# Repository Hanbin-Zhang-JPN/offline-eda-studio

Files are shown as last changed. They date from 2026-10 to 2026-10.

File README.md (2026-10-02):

# Offline EDA Studio

面向 MacBook 的原生、离线 EDA 工作台。项目目标是在明确的验收矩阵上达到 Altium Designer **90% 以上**功能覆盖；当前交付是 **v0.1.1 可运行基础版本与完整开发设计，不是已经达到 90% 的替代软件**。

原理图、PCB 编辑、交互布线、3D 与仿真使用本地 KiCad 引擎。SwiftUI 工作台补充项目管理、采购 BOM、点对点线束、SHA-256 快照和制造发布流水线。工作台没有网络客户端、云账号、遥测或在线激活。

## 当前可运行的功能

- 原生中文 macOS 界面与 CLI，打开/创建自包含项目，启动 KiCad 原理图和 PCB 编辑器。
- PCB 简化只读预览：真实文件里的直线、走线和矩形焊盘，前/后铜层切换。
- 本地采购元件增删、搜索、计划 DNP、分组 CSV。采购计划不自动同步原理图；设计 BOM 从 KiCad 导出。
- 点对点线束检查与裁线 CSV：未知连接器、越界引脚、重复占针、自连接及长度检查。
- 复制前后校验的项目快照，SHA-256 清单与篡改检测。
- KiCad 作业：ERC、DRC/原理图一致性、Gerber、Excellon、坐标、STEP、SVG、PDF、网表、设计 BOM、IPC-2581、ODB++。
- 双层板制造发布：冻结输入 → 检查 → 输出 → 校验，失败保留诊断。多层板明确拒绝，避免遗漏内层铜。
- 薄导体微带阻抗初估，带参数检查与模型限制。
- 12 类、122 项功能矩阵及每项验收条件。矩阵中的继承能力、代码实现与完整验收分开记录。

## 获取和安装

要求 macOS 14 或更高。当前发布的工作台二进制为 Apple Silicon（arm64）；Intel 需自行编译，尚未完成硬件验收。

1. 从 [Releases](https://github.com/Hanbin-Zhang-JPN/offline-eda-studio/releases) 下载工作台 ZIP，解压，将 `Offline EDA Studio.app` 放进“应用程序”。
2. 从 [KiCad 官方 macOS 下载页](https://www.kicad.org/download/macos/) 获取 KiCad 10.x，按官方说明安装完整 KiCad 文件夹，保留内置符号、封装及 3D 模型。验证基线为 10.0.6。
3. 打开工作台，默认自动查找 `/Applications/KiCad/KiCad.app/Contents/MacOS/kicad-cli`。自定义安装位置可用“选择 EDA 引擎”。
4. 点击“新建示例”，选择新目录；打开原理图或 PCB 编辑器，编辑并保存后回到工作台刷新。
5. 准备好本地模型后断网，检查、快照、CSV 和制造输出仍可运行。演示项目自带原创符号与封装，演示检查不依赖外部元件库。

工作台包使用本地 ad-hoc 签名，尚未 Developer ID 签名和公证。首次启动可在 Finder 右键“打开”，由 macOS 安全设置决定是否允许；不要求关闭系统保护。工作台 ZIP 不含 KiCad 二进制，完整离线安装需提前准备 **两个包**及所需模型。仓库提供固定版本下载和 SHA-256 校验脚本。

## 从源码编译

安装 Xcode Command Line Tools（或 Xcode）、Python 3；Swift 5.9+。无 npm、第三方 Swift 包或在线运行时依赖。首次安装开发工具需要网络；准备好的源码可离线编译。

```bash
./scripts/prepare-resources.sh
./scripts/swift.sh build
./scripts/swift.sh run EDASelfTests
./scripts/build-app.sh
open "dist/Offline EDA Studio.app"
```

`scripts/swift.sh` 会在本机 CLT 的预览 SDK 缺少 State 宏插件时选择已安装的稳定 SDK；可通过 `EDA_SDK=/path/to/sdk` 显式指定。产物在 `dist/`。测试程序不依赖完整 Xcode 中的 XCTest，可在 CLT 环境运行。

## CLI

```bash
.build/debug/eda create /tmp/led-design "我的 LED 板" examples/led-demo
.build/debug/eda doctor
.build/debug/eda inspect /tmp/led-design
.build/debug/eda snapshot /tmp/led-design "布局完成"
.build/debug/eda bom /tmp/led-design /tmp/planning-bom.csv
.build/debug/eda harness /tmp/led-design /tmp/wires.csv
.build/debug/eda job /tmp/led-design drc /tmp/check
.build/debug/eda release /tmp/led-design --step
.build/debug/eda impedance 0.30 0.18 4.2
```

可以用 `KICAD_CLI=/path/to/kicad-cli` 指定引擎。制造发布的 `release.json` 包含源哈希、输出哈希、引擎版本、命令、日志与退出码。`outputs/job-*` 是单项输出，**不等于通过发布**。`outputs/failed-*` 是诊断目录。

## 实现边界

高级 SI/PI 场求解、复杂刚柔结合、多板 3D 装配、正式装配变体、受管元件库、Draftsman 等效文档和原生 Altium 无损往返尚未完成。上游编辑器的功能存在不意味着本仓库已经逐项验收。当前预览不显示全部 PCB 几何；采购计划 DNP 不修改 KiCad 变体；输出检查不能替代独立 DFM 或器件电气验证。

v0.1 发布流水线只支持双层板，使用启用的 KiCad 规则。报告中的 `ignored_checks` 列出关闭的检查；没有“自动绕过检查”的按钮。复杂项目中的外部库/3D/SPICE 依赖目前需手工准备，完整依赖锁定属于后续阶段。

## 仓库地图

|路径|内容|
|---|---|
|`Sources/EDACore`|项目、BOM、快照、线束、解析预览、KiCad 适配与制造门禁|
|`Sources/EDAStudio`|原生 SwiftUI 桌面应用|
|`Sources/EDACLI`|命令行入口|
|`Tests/EDACoreTests`|可独立运行的核心测试|
|`examples/led-demo`|可复生成的原创、自包含 KiCad 示例|
|`Resources`|功能矩阵数据和类别权重|
|`docs`|需求、系统架构、各高级模块规格、路线图、离线打包及验收|
|`scripts`|构建、校验、引擎下载、真实集成测试和资源同步|
|`reports`|本次验证证据及限制|

## 设计与验收文档

从 [产品需求](docs/PRODUCT_REQUIREMENTS.md)、[系统架构](docs/ARCHITECTURE.md)、[122 项功能矩阵](docs/FEATURE_MATRIX.md) 和 [分阶段路线图](docs/ROADMAP.md) 开始。具体模块规格位于 [docs/specs](docs/specs)，当前运行说明见 [macOS 安装](docs/MACOS_INSTALL.md)、[离线使用](docs/OFFLINE.md)、[测试方案](docs/TESTING.md)。

本项目与 Altium、KiCad 官方无从属关系。原创代码和示例为 MIT 许可；外部引擎保留各自许可证，见 [第三方说明](THIRD_PARTY.md)。

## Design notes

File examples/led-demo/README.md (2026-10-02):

# 自包含 LED 示例

原始演示数据，符号与封装均由本仓库生成，不依赖外部元件库。J1.1 为 3.3 V 输入，J1.2 为地；R1 330 Ω 与 D1 串联。图形是通用两引脚演示符号，未替代真实 LED 符号及器件电气模型。板上封装、极性、电流与器件料号必须按实际采购器件重新设计和验证，不可直接投产。线束数据为独立点对点示例，J2 是外部电源连接器。采购单价 0 表示未录入报价。

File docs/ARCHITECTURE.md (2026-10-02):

# 系统架构

## 已实现架构

```mermaid
flowchart LR
    UI[SwiftUI macOS 工作台] --> Core[EDACore]
    CLI[eda CLI] --> Core
    Core --> Data[项目 JSON / SHA-256 快照]
    Core --> Runner[参数数组 / 超时 / 日志文件]
    Runner --> Engine[KiCad 10 CLI]
    UI --> Editors[KiCad 原生编辑器]
    Engine --> Outputs[报告 / 制造文件 / 三维导出]
```

工作台没有 HTTP/WebSocket 客户端或服务端。进程适配器直接运行本地二进制，使用参数数组避免 shell 注入，stdout/stderr 写临时文件防止管道缓冲死锁。检测超时后先 terminate，必要时 kill 并等待子进程退出。GUI 将耗时工作放到后台任务，不在主线程执行 DRC。

### 模块职责

|模块|责任|禁止行为|
|---|---|---|
|Models|schemaVersion、路径边界、元数据原子保存、BOM 分组|重写原理图或隐式改料|
|ProjectFiles|排除生成目录、复制前后哈希、快照校验|跟随符号链接把外部文件打包|
|Harness|连接器/针脚/导线数据与点对点检查|假定独立线束已同步 PCB|
|BoardPreview|有边界的 S-expression 解析和几何摘要|用于制造或电气拓扑判定|
|Engine|引擎探测、版本握手、CLI 作业、日志与超时|默认兼容未知主版本|
|Manufacturing|冻结、规则检查、证据校验、唯一发布目录|把失败输出标为 release|
|AppModel|最近项目、文件选择、后台作业、编辑器启动|上传项目或自动下载依赖|

### 设计权威与一致性

`.kicad_sch/.kicad_pcb/.kicad_pro` 是设计权威文件。工作台元数据、采购计划、线束资料独立存储。当前 DNP 仅作用于采购计划，原理图权威 BOM 独立导出。发布 DRC 包括 `--schematic-parity`，但程序不能代替器件电气、工艺能力和人工批准。

当前 Snapshot 将所有非生成源文件复制进不可变目录，并核对复制前后和目标的散列；恢复时用户复制 source 到新目录。复杂外部依赖尚未自动解析，不可宣称完整工程闭包。

## 目标架构（待实现）

```mermaid
flowchart TB
    Desktop[SwiftUI / AppKit] --> Service[项目与设计服务]
    Service --> DB[可重建 SQLite 索引]
    Service --> Registry[本地受管库 / 内容寻址资源]
    Service --> Jobs[任务依赖图 / 发布审计]
    Service --> IPC[KiCad IPC 文档化适配器]
    Service --> Advanced[约束 / 变体 / 线束 / 多板 / 刚柔]
    Advanced --> Geometry[OCCT 几何与碰撞进程]
    Advanced --> Solver[本地 SI/PI/SPICE 适配器]
    Jobs --> Package[离线交付清单 / SBOM / 签名]
```

1. 服务层使用 actor 隔离项目操作；每个项目单写者，读取使用明确 revision ID。
2. 原生设计文件保存后计算 design revision；所有结果绑定 revision、库锁文件、规则哈希和引擎版本。
3. 任务图按输入签名缓存，但任何门禁结果不得跨不同源/库/规则复用。
4. 几何、仿真、插件独立进程；崩溃或许可证缺失不会损坏原生项目。
5. IPC 支持启动握手、API 能力查询、事务回执和保存确认；不足的 API 继续走受审查 CLI 或原生 GUI。
6. SQLite WAL 用作索引与审阅事件存储；设计本身仍是开放文件。事务失败不改变审批状态。

### 高级模块依赖顺序

库锁定 → 项目闭包 → 正式变体 → 制造完整性；原生语义抽取 → 约束 → 高速求解；OCCT 模型 → 碰撞 → 多板/弯折；系统端口 → 线束/跨板 ECO。任何一个模块只提供 JSON 模型不算完成图形编辑/专业校核。

### 项目服务 API（目标）

`openProject(URL) -> Revision`；`scanDependencies(Revision) -> ClosureReport`；`proposeECO(ChangeSet) -> Preview`；`commitECO(Preview, expectedRevision)`；`runJob(JobSpec, Revision) -> JobID`；`approveRelease(Hash, Identity)`；`exportBundle(Revision, Lockfile)`。所有写入携带 expectedRevision，防止覆盖外部编辑器的新保存。

### 可替换组件

引擎通过协议提供探测/版本/能力/作业/编辑器接口；不得将 KiCad 内部未公开类直接嵌入 SwiftUI。三维/求解器也通过声明式输入文件与结果 schema 通信，选择后锁定版本和单位。任何生成规则/仿真约束回写先出差异预览。

### 已知工程债

工作台当前使用全文件读取、数组型采购计划和极简预览；大型工程需要流式解析/索引。作业暂不可主动取消；只有超时。外部库闭包/恢复事务/多层出图/完整 DFM/批准签名尚未实现。不得把这些债项隐去以宣称 90%。

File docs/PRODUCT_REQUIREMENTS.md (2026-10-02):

# 产品需求与边界

## 产品目标

为 MacBook 提供无需联网、账号或激活的电子产品设计工作流。从捕获电路、元件选择、多层 PCB、布线、验证、3D、装配变体、制造文档到本地版本审阅保持数据可追溯。KiCad 原生文件为单板设计权威数据，工作台不能通过自建简化格式取代电气设计。

“Altium 90%”的分母由 FEATURE_MATRIX 冻结，须由需求方认可。只对具有完整验收证据的功能计分；简单子功能数量不能冲抵复杂能力。12 类均须达到最低分数，关键高阶能力须全部通过。v0.1 当前不做达标宣称。

## 用户场景

1. 普通硬件工程师：带着已准备好的库断网，在 Mac 创建原理图、布线并交付双层/多层板。
2. 高速工程师：层叠、阻抗、差分/延时组约束、仿真证据与走线对应；不把近似计算器当场求解器。
3. 机电工程师：壳体与板框交换、装配位置变更、碰撞/干涉检查和批准事务。
4. 小型团队：本地库批准、设计快照、语义比较、评论、审批，网络同步是可选显式动作。
5. 制造工程师：读取制造网表、所有层、孔表、坐标、BOM、装配变体与可验证的交付清单。

## 当前范围（v0.1）

本地工作台、两层自包含示例、采购计划、点对点线束、不可变快照、KiCad CLI 适配和检查门禁。原生编辑发生在外部 KiCad 应用中；用户保存后刷新。单项作业输出、正式发布目录和失败诊断目录具有不同语义。

## 目标范围（待实现）

四层以上制造流水线、完整依赖锁定/迁移、正式装配变体、受管库、IPC 编辑事务、约束管理、多板装配、刚柔区域和折叠、线束图形编辑、SI/PI 求解集成、生产文档生成、离线审阅/批准。实时供应链服务不能离线等效，只支持带时间戳的导入镜像。

## 非功能指标（目标，尚未实测验收）

|项目|目标|
|---|---|
|平台|macOS 14+，arm64 和 x86_64 独立验证|
|安装|签名/公证 app；离线完整包有 SHA-256 和 SBOM|
|启动|基准 16 GB M 系列机器，空工作区冷启动 ≤3 秒|
|交互|常规 5000 元件 PCB 交互保持 ≥30 FPS；更大项目提供降级/分页|
|索引|10 万元件搜索 P95 ≤150 ms，事务与索引可重建|
|制造|输出哈希可重复；时间戳或引擎非确定字段明确分离|
|安全|不运行 shell 拼接字符串；越界路径/不受信插件可拒绝|
|网络|断网核心流程全通过，无隐式远程下载/遥测|
|保全|原子保存、快照校验、磁盘满/崩溃/超时测试无设计覆盖|
|可访问性|键盘、VoiceOver、中文/英文、缩放和高对比度|

## 数据所有权

项目为用户可直接读取的目录，元数据 JSON、设计为 KiCad 原生文件、未来索引 SQLite 为可重建副本。禁止强制云格式、暗中更换元件库和自动上传电路。程序不得将“导入成功”表述为“电气等价”，必须输出差异报告。

## 完成判定

完整闭环不是仅有按钮：需要正/负夹具、导出独立验证、断网测试、Mac 两架构安装测试、清洁机器迁移、故障注入与需求签收。详细门禁见 TESTING。未完成項目不能在功能矩阵里标为 verified。

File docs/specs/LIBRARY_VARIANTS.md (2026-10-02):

# 受管元件库、采购和装配变体

状态：v0.1 为手工采购计划；专业管理与正式变体待实现。

## 三种对象必须分开

- DesignComponent：原理图/PCB 的权威实例，包含网络、封装和电气属性。
- ProcurementPlan：参考位号、MPN、厂商、离线报价和库存。当前 parts.json 即此对象。
- AssemblyVariant：指定设计 revision 上的 DNP/替代料规则，必须同时作用于坐标、BOM、装配图、3D 与制造文档。

采购计划删除/DNP 不改变原理图。正式变体解析器输出 EffectiveAssembly，并被所有作业共用，不允许每个导出脚本独立解释 DNP。

## 本地受管库（目标）

元件 UUID 的每个批准 revision 绑定符号/封装/模型内容哈希、参数单位、生命周期、来源/许可、数据表和审核记录。草稿可以编辑，批准版本不可原地改变；项目通过锁文件引用 revision。SQLite 搜索索引可重建，资源以内容寻址保存。

参数含数量、单位、容差与比较区间；检索结果区分 unknown 和 zero。批准替代料要满足封装/焊盘映射、额定值、容差、温度和高度约束。MPN 字符串相近不能自动替换。

## 离线报价

QuoteSnapshot：供应商、币种、单位、阶梯数量、包装、最小订购量、库存、采集时间、来源。用户主动导入，显示时效；缺报价不计算为 0 成本。批次计算包含单位数量、损耗和包装取整，公式和币种转换资料可审查。不承诺断网实时 ActiveBOM。

## 必需异常测试

重复位号/跨板 ID、引号和换行字段、同 MPN 不同封装、价格分组、缺币种、替代料针脚错配、DNP 坐标遗漏、多变体导出错用、库锁缺失和批准记录冲突。清洁 Mac 不配置全局库即可重开锁定工程。

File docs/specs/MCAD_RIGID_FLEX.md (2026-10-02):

# 三维、机电与刚柔结合

状态：KiCad 提供本地 3D/STEP 导出，工作台可执行 STEP 作业；复杂机电协同与刚柔设计待实现。

## 几何基础

建议独立 OCCT 服务进程，输入为锁定 STEP 模型、板框、叠层、元件变换和公差。统一 mm 与右手坐标系；变换使用明确 4×4 矩阵，所有源坐标转换可追溯。模型缺失显示占位和诊断，不把没有模型的空间当无碰撞。

实体/面选择锚点不能只用导入时的数组下标，需关联设计 UUID 与稳定几何签名。引擎更新后拓扑改变的锚点标记失效。

## 双向 ECO

板框/孔/元件位置 → MCAD → 提案 → 差异预览 → 容差/约束检查 →批准 → 原生设计提交。来自外部机械工具的修改必须携带 revision/模型哈希；PCB 已变化时不直接合并。STEP 交换本身不是实时 CoDesigner 等价能力。

## 刚柔区域模型

Stackup 记录铜/介质/覆盖膜/加强片的材料、厚度、层范围与压合序列；Region 为可验证多边形、子叠层 ID、刚/柔类型和优先级；Bend 包含轴、半径、角度、顺序、适用区域与中性面参数。重叠/嵌套区不能用单一板厚处理。

展开/折叠在固定坐标映射上变换几何，保留元件/铜/孔锚点。通过材料厚度和弯曲半径计算路径，但柔性材料的真实力学可靠性需要工程规则与厂商验证，不由 3D 外观决定。

## 检查

区域无意重叠/未覆盖、层集合冲突、柔区过孔和尖角、弯折区元件/铜规则、折叠实体干涉、最小弯折半径与覆盖膜开口。输出展开轮廓、分区叠层、覆盖膜、加强片和钻孔/压合组，与制造商黄金资料对照。

## 多板装配

每个 board instance 具有 designRevision、变换和连接器锚点；配合约束包括平面、同轴、距离、角度和端口。约束图避免环形过约束，求解失败有解释。装配碰撞与系统连接图同 revision，不可用旧板模型批准新系统。

## 关键验收

STEP 独立导入和单位核对、已知干涉/间隙、模型缺失、PCB 外部编辑冲突；单/多弯折、重叠子叠层、开槽与书本结构、展开恢复、刚柔制造文件。未实现折叠/制造映射前，FLEX 类保持 planned。

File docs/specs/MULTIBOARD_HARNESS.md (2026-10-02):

# 多板系统与线束

状态：v0.1 有独立点对点数据、检查和裁线 CSV，没有多板 3D 和线束图形编辑。

## 系统数据

SystemProject 包含 BoardInstances、Ports、Interconnects 和 Assembly。每个端口绑定板实例 ID、元件 UUID、针脚映射、信号类型、电压/电流等级及匹配接插件；跨板重复位号用 BoardID:Reference 区分。网络名相同不自动意味着系统连通。

连接类型：直接板对板、线缆、线束、柔性连接；都须有针脚对照和电气类型检查。板接口 ECO 改动触发相关线束/系统连接过期，制造发布需重新审核。

## 线束专业模型

Connector 的引脚、壳体、端子和防呆方向；Wire 的线径、绝缘、颜色、长度和公差；Splice 作为显式分支节点；Shield、TwistedPair、Sleeve、Branch 与 TerminalCrimp 独立对象。导线长度分开路由几何长度、加工余量和裁线长度，计算规则可审查。

v1 的重复占针拒绝用于点对点；未来支持分支必须通过 Splice，不直接放开唯一性规则。检查包含未知端点、引脚越界、自连接、错误网、端子兼容、接插件性别/方向、额定电压电流、线径与压接范围、屏蔽接地及分支连接。

## 图形编辑与文档

2D 系统连接/线束路由编辑支持选择、吸附、弯折/分支、撤销事务、端口高亮和电气问题定位。制造图提供端面朝向、线色/针脚/端子、套管、长度公差、压接和治具资料；裁线 CSV 只是其中一项。

## ECO

板连接器改变 → 系统端口差异 → 线束受影响对象 → 可审查修复映射 → 系统/板/线束统一批准 revision。不能仅按名字猜测针脚；未分配针脚与错配作为阻塞问题。

## 验收

直连/交叉针脚、重复板、错误性别、越界、线径压接、分支/屏蔽/绞对、线长/余量、接口版本冲突、BOM 聚合、3D 端口映射与制造图核对。当前演示 J2 是外部连接器，数据尚未自动与 PCB 原理图同步。

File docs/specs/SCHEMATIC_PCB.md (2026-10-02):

# 原理图、PCB 与约束规格

状态：单板编辑使用 KiCad；以下专业流程待逐项验收或实现。

## 权威数据与编辑

SchematicDocument 保留符号 UUID、层次页路径、引脚、电气类型、总线/网络名与元件字段。BoardDocument 保留封装 UUID/原理图 path、铜层、焊盘、走线、过孔、区域、叠层和规则。工作台预览只读，不得参与网络抽取；权威网表和 DRC 由引擎提供。

IPC 服务启动时查询能力与主版本，提交事务携带 expectedRevision 和操作列表，成功后要求保存回执、重新读取网表/哈希。多窗口编辑有外部文件变更检测；冲突不以时间戳更近自动取代。

## ECO 流程

原理图修改 → 网表/封装映射提取 → 新增/删除/改值/改封装/改网的差异预览 → 用户批准 → 引擎提交 → ERC/DRC/一致性检查 → 保存新 revision。删除元件不能悄悄留下无主铜；换封装必须审查焊盘映射和三维高度。

## 约束模型

ConstraintSet：网络类、对象选择器、区域、适用层、优先级、值及单位。规则冲突采用确定性顺序：显式对象规则 > 区域规则 > 网络类 > 全局默认；未实现前使用原生引擎规则。每个对象可查询规则命中的解释。

包含线宽、铜距、孔径/环宽、层对、差分间距/偏差、线长、延时组、禁布/禁高、阻焊/钢网。延时不是简单几何长度，需要介质、层叠、过孔和求解模型；无法评估时报告 unsupported，禁止推断通过。

## 多层制造

导出时从板配置枚举所有启用的铜层和工艺层，核对 Gerber 数量/层名、钻孔层对和叠层声明。盲埋/微孔记录压合组；板形、槽孔、工艺边进入文档。v0.1 只允许 F.Cu/B.Cu，四层以上必须在原生 KiCad 审核导出，直到多层漏层负测试通过。

## 专业验收

层次/总线/多单元黄金网表；BGA 推挤和撤销；差分过孔、蛇形线长/延时；HDI 层对；覆铜热连接与孤岛；4/16/32 层制造包；10 万焊盘性能；跨探测和编辑器保存回执。文件可读、图形漂亮或单板零违规都不足以完成这些验收。

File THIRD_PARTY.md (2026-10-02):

# 第三方组件与来源

本仓库原创 Swift 代码、生成脚本、文档、符号/封装与示例采用 MIT。SwiftUI、AppKit、Foundation、CryptoKit 是系统框架，本仓库不分发其源码或系统运行时。

KiCad 是独立外部引擎，工作台通过文档化命令行和外部应用入口调用，不包含 KiCad 源码或可执行文件。官方 DMG 通过 fetch-engine.sh 单独获取，engine/ 被 Git 忽略，不随工作台 ZIP/GitHub 源码发布。KiCad 及其内置 Python、wxWidgets、ngspice、几何与其他资源的许可声明以官方安装包和上游源码为准；重新捆绑引擎必须保留全部相应许可和源码提供要求，不能把引擎改称本项目 MIT 代码。

固定引擎来源：

- [KiCad 10.0.6 官方 Release](https://github.com/KiCad/kicad-source-mirror/releases/tag/10.0.6)
- 文件：kicad-unified-universal-10.0.6.dmg
- SHA-256：ef4dcd4278c46d3efcd28c8db273d5957d68efda028f6bf79b4811fc5302dc68
- [KiCad macOS 安装](https://www.kicad.org/download/macos/)
- [KiCad CLI](https://docs.kicad.org/10.0/en/cli/cli.html)

Altium Designer、Altium 与 KiCad 商标属于各自权利人。没有复制 Altium 商业代码、图标、界面素材或示例，文档只进行功能范围对标，不宣称官方认可。未来第三方求解器/几何/库资源应增加 SPDX、来源和 SBOM；当前仅是设计规格，未暗中下载这些组件。

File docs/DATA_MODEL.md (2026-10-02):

# 数据模型与存储

## 已实现格式

项目目录至少包含 eda-project.json、设计文件、parts.json、harness.json。manifest schemaVersion=1，name 不为空，所有字段均为项目内相对路径。绝对路径、`..`、解析到根外的符号链接被拒绝。设计文件使用 KiCad 原生格式，不由工作台更改电气结构。

```json
{"schemaVersion":1,"name":"LED","projectFile":"design.kicad_pro","schematicFile":"design.kicad_sch","boardFile":"design.kicad_pcb","partsFile":"parts.json","harnessFile":"harness.json"}
```

parts.json 是 Component 数组：reference/value/footprint/mpn/manufacturer/unitPrice/dnp。每个位号一条，忽略大小写的重复位号拒绝；价格必须非负有限数。数量由分组得到，组键包含值、封装、MPN、厂商、单价及 DNP。单价当前没有币种，是采购计划字段，不能作为实时采购计算。

harness.json 包含 schemaVersion、connectors 与 wires。连接器有 id/pins/partNumber；导线有 id/from/to/net/lengthMM/awg/color。v1 是点对点模型，一个端点不允许被多根线占用；分支需要未来显式接点模型，不能靠重复占针代替。

### 快照

`.eda-snapshots/<uuid>/snapshot.json` 记录时间、标签、每个源文件路径/字节数/sha256，source/ 复制源。排除 outputs、快照自身、Git、构建产物、引擎、备份和 KiCad 临时偏好文件。复制前后输入以及复制目标必须一致，不一致则清理临时目录。校验要求文件集合也一致，新增/删除/修改均导致失败。

### 作业与发布

单项作业：outputs/job-*/command.json。发布：outputs/release-*/release.json + source/ + artifacts/；失败：outputs/failed-*。命令含参数、退出码、stdout/stderr、耗时。发布清单包含源/输出哈希、引擎版本、status 与 note。UUID 命名确保不同运行不覆盖输出。

元数据使用原子写入。当前无多进程写锁，外部同时修改 parts.json 可造成最后写入胜出；生产级项目 actor 和 expectedRevision 属于 P2，不能声称已解决并发编辑。

## 未来服务数据模型

|实体|关键字段|不变量|
|---|---|---|
|DesignRevision|source hashes、libraryLockHash、ruleHash、engineVersion|审批和结果绑定相同 revision|
|ManagedComponent|UUID、revision、symbolHash、footprintHash、modelHash、parameters、status|批准版本不可原地覆盖|
|Variant|baseRevision、component overrides、DNP、alternative ID|每种输出采用同一个变体解析结果|
|ECO|expectedRevision、operations、previewHash、author|提交前验证 revision，无静默冲突|
|Assembly|board instance ID、4x4 transform、mates|坐标/单位统一、禁止循环配合|
|FlexRegion|polygon、stackup ID、bend definitions|区域与层集合明确，展开/折叠可逆|
|ReviewEvent|object anchor、revision、identity、time、action|失效锚点不能错误指向新对象|
|JobSpec|input hashes、capabilities、tool version、outputs|缓存键包括所有设计/依赖/规则|

SQLite 仅作索引、可重建视图与审阅事件，启用 foreign keys/WAL 和事务。几何使用 KiCad 原生精度或整数 nm；求解器边界转换用显式单位，不能混用 mil/mm。文件 schema 迁移先备份再生成新版本，不原地升级用户原稿。

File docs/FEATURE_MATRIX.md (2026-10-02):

# Altium Designer 功能对标与验收矩阵

基线：2026-10-03 阅读的官方功能资料；不是 Altium 官方的全量功能目录或等效认证。

**目标 ≥90%，当前尚未达成。** status 为 implemented 表示已有代码；inherited 表示引擎拥有相关能力但没有完成本仓库验收；planned 表示只有规格。只有 verified 状态且证据包含版本、平台、正常/异常夹具、人工验证与可复现结果时，才计入验收覆盖率。单个 LED 示例通过不代表完整生产级能力通过。当前所有功能仍待完整验收，因此验收分数为 0%，这不代表引擎没有功能。

## 计算方法

每个类别内按 weight 加权，再按类别占比汇总。分母冻结，不移除难题或把云能力悄悄排除。支持的离线等效流程需单独验收，不能称实时服务等效。

`总分 = Σ 类别占比 × Σ(功能权重 × verified) / Σ(功能权重)`

发布“达到 90%”还必须：每一类别 ≥80%；原理图、PCB、制造、库管理、SI/PI、刚柔结合、多板/线束全部通过关键功能；断网从编辑到制造全流程、资料往返一致性与独立 DFM 验证通过；没有数据损坏、开短路、单位/坐标错位的 P0/P1 缺陷。用户认可该分母后才可用于产品宣称。90% 不是界面相似度、代码行数或按钮数量。

## 类别权重

|类别|占比|
|---|---:|
|原理图|14%|
|PCB 编辑与布线|20%|
|符号/封装/元件库|9%|
|制造与文档|11%|
|采购与装配变体|6%|
|仿真与信号完整性|9%|
|三维与机电协同|7%|
|刚柔结合|7%|
|多板系统与线束|7%|
|项目与数据管理|5%|
|兼容与自动化|3%|
|Mac 与离线交付|2%|

## 功能清单

|ID|类别|功能|权重|状态|阶段|验收条件|
|---|---|---|---:|---|---|---|
|SCH01|原理图|交互放置与连线|2|inherited|P1|在 Mac 创建 100 元件电路并连线，保存重开、撤销重做均一致|
|SCH02|原理图|层次式多页设计|2|inherited|P1|建立三级层次、重复子页，生成网表后端口网络映射与黄金数据一致|
|SCH03|原理图|总线与总线别名|2|inherited|P1|8 位总线展开后成员网络正确，别名更名不造成短接|
|SCH04|原理图|注释与位号编排|2|inherited|P1|重复、缺失位号能诊断，自动编排支持保留固定编号|
|SCH05|原理图|符号字段与属性|2|inherited|P1|批量修改 MPN、容差、额定值，PDF 与 BOM 字段保留|
|SCH06|原理图|电气规则检查|2|inherited|P1|好坏电路各 10 类错误，错误类型与定位正确，违规退出非零|
|SCH07|原理图|网络标签和全局端口|2|inherited|P1|同名局部网络隔离、全局网络贯穿层次，测试无隐式短接|
|SCH08|原理图|多单元与隐藏电源脚|2|inherited|P1|多单元运放含电源单元的网表及位号分配正确|
|SCH09|原理图|差分对网络定义|2|inherited|P1|网络命名与 PCB 差分对约束映射一致|
|SCH10|原理图|原理图到 PCB 同步|2|inherited|P1|新增、删除、改封装后 ECO 可预览并准确同步|
|SCH11|原理图|跨探测与对象高亮|2|inherited|P1|在原理图选择位号或网络，PCB 编辑器定位对应对象|
|SCH12|原理图|电路复用与设计块|2|inherited|P1|重复插入设计块，网络与位号隔离、属性模板一致|
|SCH13|原理图|SPICE 模型关联|2|inherited|P1|本地模型目录可移植，未安装模型时报缺失路径|
|SCH14|原理图|PDF/SVG/网表输出|2|inherited|P1|离线输出含层次与字段的文档，PDF 阅读器和网表工具可读|
|PCB01|PCB 编辑与布线|多铜层布局|3|inherited|P1|2/4/16/32 层测试板保存重开、图层可见性与规则正确|
|PCB02|PCB 编辑与布线|板框与切割轮廓|3|inherited|P1|含圆弧、内开槽板框，闭合检查和 STEP 几何一致|
|PCB03|PCB 编辑与布线|交互推挤布线|3|inherited|P1|密集 BGA 场景推挤、绕障、撤销，实时规则无短路|
|PCB04|PCB 编辑与布线|差分对布线|3|inherited|P1|成对走线、过孔、间距约束，在制造网表中两网独立|
|PCB05|PCB 编辑与布线|长度调谐|3|inherited|P1|蛇形布线按目标长度误差验证，折线/圆弧长度计算正确|
|PCB06|PCB 编辑与布线|传播延时与组内偏差|3|inherited|P1|指定介质与走线层后延时调谐满足预算，以基准工具核对|
|PCB07|PCB 编辑与布线|网络类与区域规则|3|inherited|P1|相同网络在不同区域 应用不同线宽，规则优先级可解释|
|PCB08|PCB 编辑与布线|过孔与盲埋孔|3|inherited|P1|层对、孔径、盲埋孔规则，输出钻孔与叠层对照正确|
|PCB09|PCB 编辑与布线|微孔与 HDI|3|inherited|P1|多次压合测试板检查层对、环宽、微孔堆叠，制造商可审核|
|PCB10|PCB 编辑与布线|覆铜与热焊盘|3|inherited|P1|孤岛、热辐条、keepout 与填充版本的连接检查一致|
|PCB11|PCB 编辑与布线|自定义焊盘与泪滴|3|inherited|P1|任意焊盘、圆角、泪滴几何制造后正确，无额外短路|
|PCB12|PCB 编辑与布线|布局对齐与分布|3|inherited|P1|锁定组件、阵列、对齐、旋转复制后位置精度符合要求|
|PCB13|PCB 编辑与布线|交互 DRC|3|inherited|P1|布线时诊断线宽、间距、过孔，关闭提示不关闭发布门禁|
|PCB14|PCB 编辑与布线|完整批量 DRC|3|inherited|P1|错误、警告、未连线、原理图一致性检查可定位并阻止发布|
|PCB15|PCB 编辑与布线|约束管理器|3|inherited|P1|设计规则编辑、冲突优先级和对象适用范围有可查询解释|
|PCB16|PCB 编辑与布线|铜层与阻焊/钢网|3|inherited|P1|阻焊扩展、钢网缩减、非金属化槽与出图数据一致|
|PCB17|PCB 编辑与布线|禁布区与机械区域|3|inherited|P1|规则区域独立控制焊盘、过孔、走线和元件，覆盖优先级稳定|
|PCB18|PCB 编辑与布线|面板化与工艺边|3|inherited|P1|阵列、V-cut、连接桥、基准点、钻孔映射可与工厂资料对照|
|PCB19|PCB 编辑与布线|自动布线适配器|3|inherited|P1|可选离线布线器读取 DSN 返回 SES，导入后重新做 DRC|
|PCB20|PCB 编辑与布线|RF 与曲线布线|3|inherited|P1|圆弧、曲线、射频几何可输出，阻抗和制造容差独立校验|
|PCB21|PCB 编辑与布线|大板性能|3|inherited|P1|10 万焊盘/100 万线段测试，记录内存、交互帧率与 DRC 用时|
|PCB22|PCB 编辑与布线|撤销事务与崩溃恢复|3|inherited|P1|100 次连续编辑撤销后几何与网表一致，崩溃不损坏最后保存|
|LIB01|符号/封装/元件库|符号编辑器|2|inherited|P2|本地多单元符号编辑、引脚类型与字段一致，通过独立库规则检查|
|LIB02|符号/封装/元件库|封装编辑器|2|inherited|P2|SMD/THT/自定义焊盘、庭院、制造层和 3D 关联可编辑|
|LIB03|符号/封装/元件库|本地受管元件库|2|planned|P2|将符号、封装、模型、资料按不可变版本管理，项目锁定版本|
|LIB04|符号/封装/元件库|参数搜索与过滤|2|planned|P2|10 万元件按 MPN/封装/参数查询，结果可离线重复|
|LIB05|符号/封装/元件库|库发布和审查|2|planned|P2|草稿、审查、批准、废弃状态有本地审计，未批准零件不得正式发布|
|LIB06|符号/封装/元件库|缺库与缺模型检测|2|planned|P2|迁移到清洁机器断网，准确列出缺失资源，不能静默改库|
|LIB07|符号/封装/元件库|IPC 封装生成器|2|planned|P2|QFN/QFP/BGA 参数生成后与黄金几何、命名及庭院对照|
|LIB08|符号/封装/元件库|数据库导入导出|2|planned|P2|SQLite/CSV 数据可校验并迁移，事务失败不产生半条元件|
|LIB09|符号/封装/元件库|替代料与生命周期|2|planned|P2|替代料具有封装、电气审核记录，不靠字符串相同自动换料|
|LIB10|符号/封装/元件库|原生库转换|2|planned|P2|受支持的 Altium/EAGLE 库导入有失真报告，原文件保留|
|LIB11|符号/封装/元件库|数据表与本地模型包|2|planned|P2|PDF、SPICE、STEP 依赖打包到项目，哈希校验和相对路径可移植|
|MFG01|制造与文档|Gerber X2 输出|2|implemented|P1|所有已用铜层和工艺层完整，独立 Gerber 查看器核对层和网络属性|
|MFG02|制造与文档|Excellon 钻孔|2|implemented|P1|金属/非金属孔分离、坐标单位、孔表与板上孔逐一核对|
|MFG03|制造与文档|贴片坐标与装配原点|2|implemented|P1|上下表面旋转/镜像和原点在装配器件黄金数据中正确|
|MFG04|制造与文档|设计 BOM 与采购计划|2|implemented|P1|权威设计 BOM 从原理图导出，手工采购 CSV 分组、DNP、字段正确|
|MFG05|制造与文档|制造输出作业集|2|implemented|P1|冻结输入、ERC/DRC 门禁、唯一运行目录与哈希清单，失败不标记通过|
|MFG06|制造与文档|IPC-2581 输出|2|implemented|P1|输出文件经独立读取器或代工厂导入，网络、层、钻孔、元件一致|
|MFG07|制造与文档|ODB++ 输出|2|implemented|P1|归档结构被独立工具识别，坐标、叠层、单位与黄金板匹配|
|MFG08|制造与文档|IPC-D-356 网表|2|planned|P1|输出电气测试点与原始连通数据一致，独立比较无新增开短路|
|MFG09|制造与文档|装配与钻孔图纸|2|planned|P1|自动图框、孔表、装配位号、极性和 DNP 与设计一致|
|MFG10|制造与文档|Draftsman 等效文档|2|planned|P1|尺寸、剖面、叠层、表格、视图引用可更新，输出 PDF 无溢出|
|MFG11|制造与文档|拼板文档包|2|planned|P1|拼板、工艺边、板号和制造参数的一套输出可审核及追溯|
|MFG12|制造与文档|DFM 与可制造性|2|planned|P1|按厂商能力集检查孔铜距、阻焊桥、环宽和叠层，误报需可复核|
|MFG13|制造与文档|制造版本追溯|2|planned|P1|每个交付件可追溯引擎、源文件、库版本、规则、批准记录|
|MFG14|制造与文档|交付包签名与校验|2|planned|P1|更改任意输出后验包失败，签名与身份记录在离线环境可核验|
|BOM01|采购与装配变体|BOM 分组与排序|2|implemented|P0|字段引号/逗号/换行、不同价格、同名不同封装分组稳定|
|BOM02|采购与装配变体|采购计划 DNP|2|implemented|P0|DNP 只影响本地采购计划；界面和 CSV 明确不自动修改设计|
|BOM03|采购与装配变体|正式装配变体|2|planned|P2|同项目多变体联动原理图、PCB、坐标、BOM、装配 PDF 的 DNP|
|BOM04|采购与装配变体|替代料一致性|2|planned|P2|替换元件后封装、电气参数和采购字段一致，非法替换被阻止|
|BOM05|采购与装配变体|本地报价和库存|2|planned|P2|导入带日期与币种的快照，显示数据时效与缺失报价|
|BOM06|采购与装配变体|成本与数量展开|2|planned|P2|批量生产数量、损耗、最小包装按可审查公式计算|
|BOM07|采购与装配变体|供应链离线镜像|2|planned|P2|用户明确导入快照，断网仍可搜索，不能声称实时库存|
|BOM08|采购与装配变体|多板 BOM 合并|2|planned|P2|跨板位号携带板 ID，变体和重复元件聚合不混淆|
|SIM01|仿真与信号完整性|SPICE DC/AC/瞬态|5|inherited|P3|三种分析对照可信仿真器，误差、模型和收敛设置存档|
|SIM02|仿真与信号完整性|仿真参数扫描|5|inherited|P3|温度/参数步进与波形指标可重复，错误收敛可定位|
|SIM03|仿真与信号完整性|本地 SPICE 模型库|5|inherited|P3|模型及许可证离线打包，子电路引脚映射有检查|
|SIM04|仿真与信号完整性|波形与测量表达式|5|inherited|P3|多波形游标、FFT、导出和时间单位一致，表达式有测试|
|SIM05|仿真与信号完整性|薄导体微带初估|5|implemented|P0|准静态公式结果与参考数值一致，边界参数拒绝，明示模型限制|
|SIM06|仿真与信号完整性|二维阻抗场求解器|5|planned|P3|微带/带状/差分/阻焊求解对照基准，误差预算及收敛曲线达标|
|SIM07|仿真与信号完整性|SI 反射/串扰/眼图|5|planned|P3|IBIS/S 参数与拓扑抽取，DDR/SerDes 黄金模型误差可接受|
|SIM08|仿真与信号完整性|PI 直流压降与回流|5|planned|P3|电源平面/过孔负载与基准网格对照，单位、边界及收敛正确|
|SIM09|仿真与信号完整性|电磁/热适配器|5|planned|P3|可选本地求解器版本锁定，网格、单位、结果与来源可追溯|
|SIM10|仿真与信号完整性|高速约束回写|5|planned|P3|从仿真结论到约束回写有差异审查，不能直接改生产规则|
|MCAD01|三维与机电协同|本地 3D PCB 视图|3|inherited|P3|封装模型缺失可见，旋转、截面、材料与真实板尺寸一致|
|MCAD02|三维与机电协同|STEP/GLB/VRML 导出|3|implemented|P3|独立 MCAD 软件可读，板厚、位置、角度与黄金模型一致|
|MCAD03|三维与机电协同|壳体干涉检查|3|planned|P3|已知 20 个干涉与安全间隙案例，按容差输出碰撞位置|
|MCAD04|三维与机电协同|ECAD/MCAD 交换|3|planned|P3|STEP/IDF/DXF 离线交换保留板框和元件锁定，不冒充 CoDesigner|
|MCAD05|三维与机电协同|双向机电 ECO|3|planned|P3|移动/板框修改差异可预览、拒绝、提交，冲突不静默覆盖|
|MCAD06|三维与机电协同|机械图与尺寸约束|3|planned|P3|板框、固定孔、禁高区单位一致，并映射到 PCB DRC|
|MCAD07|三维与机电协同|多格式三维装配|3|planned|P3|独立导入验证 STEP/Parasolid 替代路径，未支持格式显式拒绝|
|FLEX01|刚柔结合|分区叠层模型|5|planned|P4|刚区/柔区/重叠区域与不同层集有唯一映射，制造剖面可审核|
|FLEX02|刚柔结合|弯折与展开|5|planned|P4|弯折轴、半径、角度、层厚对比基准几何，支持恢复展开|
|FLEX03|刚柔结合|复杂嵌套和折叠碰撞|5|planned|P4|多弯折顺序、书本结构、开槽折叠与实体碰撞正确|
|FLEX04|刚柔结合|柔区制造规则|5|planned|P4|覆盖膜、撕裂保护、导线圆弧、铜量规则与制造能力对齐|
|FLEX05|刚柔结合|柔区差分与阻抗|5|planned|P4|不同子叠层的阻抗与长度规则可解释并导出制造数据|
|FLEX06|刚柔结合|刚柔制造输出|5|planned|P4|分区叠层、覆盖膜、加强片、钻孔分组与代工黄金资料一致|
|SYS01|多板系统与线束|系统连接图|5|planned|P4|板、连接器、端口和网络建模，跨板接口改动触发一致性诊断|
|SYS02|多板系统与线束|多板三维装配|5|planned|P4|独立板变换、配合和碰撞检查，修改后装配可重建|
|SYS03|多板系统与线束|点对点线束数据|5|implemented|P0|未知连接器、越界、重复占针、相同端点被诊断，合法裁线 CSV 正确|
|SYS04|多板系统与线束|图形化线束编辑|5|planned|P4|导线、屏蔽、绞线、分支、套管可编辑，撤销和存储无损|
|SYS05|多板系统与线束|线束电气一致性|5|planned|P4|电源/信号/电压/针脚映射规则与跨板网表一致|
|SYS06|多板系统与线束|线束制造文档|5|planned|P4|裁线长度、公差、压接、端子、治具图与实际物料一致|
|SYS07|多板系统与线束|系统 ECO 与 BOM|5|planned|P4|更改板上连接器后接口、线束、汇总 BOM 的审查事务一致|
|DATA01|项目与数据管理|离线项目文件与路径隔离|2|implemented|P0|项目版本检查、路径穿越和符号链接越界被拒绝，原文件不改|
|DATA02|项目与数据管理|原子保存与元数据|2|implemented|P0|断电/写失败不留下半个 manifest；格式版本有迁移链|
|DATA03|项目与数据管理|内容哈希快照|2|implemented|P0|源文件复制前后校验，重算哈希发现篡改，失败清理临时目录|
|DATA04|项目与数据管理|语义版本差异|2|planned|P2|比较元件、网络、走线、规则，避免只比较文本次序|
|DATA05|项目与数据管理|快照恢复与分支|2|planned|P2|恢复到新目录验证哈希，已有工作不覆盖，三方合并冲突可审查|
|DATA06|项目与数据管理|离线协作与审阅|2|planned|P2|本地身份、评论锚点、审阅状态离线可存档，不依赖云服务|
|DATA07|项目与数据管理|Git 集成|2|planned|P2|显式推送/拉取，离线失败不阻碍设计，密码不写入项目|
|DATA08|项目与数据管理|发布审计与批准|2|planned|P2|审批事件不可静默修改，批准对象绑定源与输出哈希|
|INT01|兼容与自动化|Altium 文件导入|2|inherited|P3|受支持文件导入后网表/几何对照并出失真报告，不承诺完整原生往返|
|INT02|兼容与自动化|EAGLE/其他 EDA 导入|2|inherited|P3|版本、符号、封装与几何差异可审查，未支持类型明确报告|
|INT03|兼容与自动化|KiCad 原生项目互操作|2|implemented|P3|项目回到原生 KiCad 可编辑，工作台不改写电气设计文件|
|INT04|兼容与自动化|CLI 与脚本接口|2|implemented|P0|全部公开命令返回可靠退出码，含空格/Unicode 路径无命令注入|
|INT05|兼容与自动化|IPC 插件和版本兼容|2|planned|P3|仅使用文档化接口，启动握手、版本协商、崩溃恢复有测试|
|INT06|兼容与自动化|批处理与自定义输出|2|planned|P3|本地任务依赖图、输入哈希、取消和可重试，不执行隐式远程脚本|
|INT07|兼容与自动化|插件隔离与权限|2|planned|P3|文件/网络/进程权限按插件声明，拒绝权限不会破坏主程序|
|MAC01|Mac 与离线交付|原生 macOS 工作台|2|implemented|P0|Apple Silicon 打包启动，项目/元件/线束/制造页面可操作|
|MAC02|Mac 与离线交付|Apple Silicon 与 Intel|2|planned|P0|两架构独立编译测试、引擎匹配；未测架构不得声称已验证|
|MAC03|Mac 与离线交付|安装包与资源内置|2|implemented|P0|app/CLI/示例/文档随包，干净机器没有源码路径仍能运行|
|MAC04|Mac 与离线交付|断网完整工作流|2|planned|P0|关闭网络后新建、编辑、检查、仿真、出图、快照，全程无外部请求|
|MAC05|Mac 与离线交付|依赖离线准备|2|implemented|P0|引擎、符号、封装、3D/SPICE 模型锁定清单并校验，缺失明确报告|
|MAC06|Mac 与离线交付|签名/公证/更新|2|planned|P0|正式 Developer ID 签名与公证、离线验证；更新需用户主动触发|
|MAC07|Mac 与离线交付|可访问性与本地化|2|planned|P0|中文/英文、键盘导航、VoiceOver、缩放和高对比度经过检查|
|MAC08|Mac 与离线交付|性能与数据保全|2|planned|P0|项目误删、超时、磁盘满和崩溃演练记录，性能与内存达到规格|

## 官方资料

- [Altium Designer 对比页（用户提供；浏览工具未成功读取）](https://www.altium.com/cn/altium-designer/compare/autodesk-eagle)
- [Altium 多板设计](https://www.altium.com/altium-designer/features/multi-board)
- [Altium 刚柔结合](https://www.altium.com/documentation/altium-designer/pcb/rigid-flex-design)
- [Altium 线束设计](https://www.altium.com/documentation/altium-designer/harness-design)
- [KiCad PCB 功能](https://www.kicad.org/discover/pcb-design/)
- [KiCad 原理图功能](https://www.kicad.org/discover/schematic-capture/)
- [KiCad 10 CLI](https://docs.kicad.org/10.0/en/cli/cli.html)
- [KiCad IPC API](https://dev-docs.kicad.org/en/apis-and-binding/ipc-api/)

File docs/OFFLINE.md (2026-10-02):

# 离线范围与资源闭包

## v0.1 实际行为

应用和 CLI 没有网络客户端。项目、采购 BOM、点对点线束、快照、计算器、引擎调用使用本地文件；新建示例的符号和封装随包。准备好的 KiCad 可在本地编辑/查看/仿真，仿真所用模型也必须本地存在。

联网阶段只有显式动作：克隆/推送 GitHub、下载引擎、安装工具链或主动获取器件资料。`fetch-engine.sh` 从官方 GitHub release 下载 10.0.6 并校验固定 SHA-256；该脚本不是应用自动运行的一部分。

## 离线准备清单

1. 工作台 app/CLI、完整 KiCad 文件夹和版本清单。
2. 符号库、封装库、3D STEP/WRL、SPICE 子电路/模型、资料 PDF。
3. 项目本地 fp-lib-table/sym-lib-table 与正确 `${KIPRJMOD}` 路径。
4. 所有自定义环境变量、场求解器和机械工具（如果项目使用）。
5. 供应链快照的来源、导入时间、币种/报价单位和替代料批准记录。

复杂外部资源当前不会被 snapshot 自动抓取。快照禁止跟随符号链接，确保不会悄悄复制工作目录以外内容。若项目依赖全局库或绝对模型路径，搬到另一台 Mac 可能缺库；必须手工形成闭包或等待 P2 的依赖锁功能。

## 目标闭包格式（P2）

`eda-lock.json`: 引擎版本和哈希、每个符号/封装/三维/SPICE 资源的来源/许可证/相对路径/哈希、变量展开结果、工作台版本、规则哈希。依赖图递归解析 SPICE `.include` 与三维替代模型，检测循环和未解析变量。索引只能引用锁定资源，缺项列成错误清单。

导出离线包前复制全部资源到 content-addressed `resources/sha256/`，重写仅允许的引用时产生可审查补丁并保留原文件。不能静默更换封装/模型。在清洁用户账户、隔离网络的 Mac 打开、编辑、检查、仿真和制造，并比对黄金数据；这才算完整工程闭包验收。

## 断网测试（待完整执行）

在系统层禁止网络，记录工作台和所有子进程网络活动。依次新建/层次原理图/多层 PCB/3D/SPICE/各输出/快照/恢复。网络断开不能造成编辑停止或激活提示。当前集成测试是本地任务验证，不等同于网络封锁抓包证据，不将 MAC04 标记 verified。

实时供应商价格、库存、云评论、在线许可不可声称离线实时等效。以用户主动导入的有日期镜像和本地审阅替代，并保留语义差异。

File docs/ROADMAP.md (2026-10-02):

# 分阶段路线图与交付门禁

本路线图是工程估算和工作分解，不是已排期或已承诺进度。达到专业 EDA 的 90% 需要持续开发、硬件验收和制造合作方验证；一个短期原型无法证明这一指标。

|阶段|成果|依赖|退出条件|
|---|---|---|---|
|P0 基础工作台|SwiftUI、CLI、离线数据、示例、快照、双层发布、CI|macOS 工具链与 KiCad 10|核心正负测试/真实导出通过；已交付 v0.1，完整 UI 与断网验收仍待扩大|
|P1 单板闭环|原生编辑流程、约束管理、多层完整出图、全部制造输出与图纸|P0|2/4/16/32 层夹具、层次电路与原理图一致性、独立制造文件复核|
|P2 数据与生产管理|受管库、依赖闭包、装配变体、语义快照差异、BOM/审批|P1|清洁 Mac 断网打开工程；变体所有输出一致；崩溃/磁盘满保全|
|P3 高速与机电|二维场求解、SI/PI、MCAD 交换/碰撞、仿真任务图|P1/P2|黄金模型误差达标，收敛与边界条件存档，独立软件互操作|
|P4 系统与刚柔|多板 3D、分区叠层/折叠、图形线束与系统 ECO|P2/P3|复杂刚柔/线束装配与制造商黄金数据一致，跨板连接检查通过|
|P5 达标发布|全部关键功能、性能、无网络、两架构、签名公证与资料|P1–P4|矩阵 ≥90%、每类 ≥80%、关键能力全部通过、无严重数据/电气缺陷|

## 推荐团队能力（估算）

需要 EDA 核心/布线约束、macOS 客户端、几何与机械、SI/PI 数值分析、库/数据/制造、测试与发布等能力。采用成熟引擎的前提下，可按约 6–10 人、18–30 个月规划初始预算，再用 P1/P2 的实测吞吐重新估算；这不是对 90% 的保证。若完全自研原理图、布线和仿真内核，范围与成本会显著增加，需重新做路线图。

## 可直接开工的后续任务

1. 为所有原生 KiCad 功能建立可复验黄金项目，完成 macOS 编辑器人工流程验证，不把上游宣称直接计分。
2. 多层板导出读取已启用 copper layer 集合，核对 Gerber/钻孔/叠层，取消 v0.1 的双层限制前必须通过漏层负测试。
3. 依赖扫描：原理图 lib_symbols、fp-lib-table/sym-lib-table、`${KIPRJMOD}`、KiCad 环境变量、模型相对路径与 SPICE includes，形成锁文件。
4. 把采购计划、设计 BOM、正式装配变体三个概念统一到可审查映射，不静默同步。
5. 把库字段/实例/网络/几何抽取成稳定语义差异，而不是文本 diff。
6. IPC API 连接与版本协商；用户授权的改动要有命令事务、回滚和保存确认。
7. 几何与求解器先建立可独立验证命令行适配，再集成 UI。

## 禁止提前通过的门禁

不因 UI 完成而通过电气功能；不因模型字段存在而通过刚柔/线束；不因 STEP 成功导出而通过机电同步；不因 CSV 能生成而通过 ActiveBOM 等效；不把离线供应链快照当实时数据；不因单个示例零违规而通过全部规则。

迭代结束需更新变更日志、未完成项、夹具版本和证据。只修改矩阵 status 不构成通过验收。

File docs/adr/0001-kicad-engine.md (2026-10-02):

# ADR 0001：采用 KiCad 本地引擎

状态：接受。日期：2026-10-03。

用户需要 MacBook 本地离线的专业 EDA。单独实现原理图、电气网表、推挤布线、规则、覆铜、三维、仿真及制造格式是长期高风险工程；已有原生跨平台引擎可让本仓库将工程资源放在离线数据管理与高级模块。

决定：以 KiCad 10 原生设计文件和本地编辑器为单板核心，SwiftUI 提供 Mac 工作台。通过文档化 CLI/未来 IPC 组合，不将未公开引擎 API 直接嵌入。锁定测试基线 10.0.6，未知主版本拒绝。

后果：v0.1 不拥有内嵌原理图/PCB 编辑器，编辑器是独立窗口；需要提前安装 KiCad；依赖上游兼容性。KiCad 的能力不自动等价于 Altium，刚柔、多板、机电同步和 SI/PI 必须独立实现和验收。矩阵保留这些难项，不能删掉后宣称 90%。

其他选择：全自研内核需重新预算；在浏览器画板无法满足专业约束；云 EDA 不符合离线目标；Wine/Windows 商业程序不是原生 Mac 替代方案。

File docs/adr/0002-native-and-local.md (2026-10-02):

# ADR 0002：原生客户端与开放本地数据

状态：接受。

采用 SwiftUI/AppKit，macOS 14+，无 JavaScript 运行时、HTTP 后端和云账号。项目目录用户可读，KiCad 文件权威，JSON 元数据可审查，未来 SQLite 仅作索引与事务数据。文件输出和快照支持无网络。

SwiftPM 不拉取第三方依赖，示例与文档打入 app。跨平台 GUI 可后续实现，不以削弱 Mac 离线与本地体验为前提。核心业务服务与 UI 分离，CLI 共用相同门禁。

取舍：最低系统 14、当前主机架构构建；Intel/最低系统需要额外测试。未来 App Sandbox 和插件权限隔离需要设计，当前不是沙箱发行版。

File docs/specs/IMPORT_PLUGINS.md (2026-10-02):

# 格式兼容与插件接口

## 导入语义

KiCad 支持的第三方格式由当前引擎确定。工作台 v0.1 不提供完整 Altium importer；用户在原生 KiCad 导入后添加工作台 manifest。原始文件永远保留。只声称已验证的版本/文件类型，未支持的对象/规则必须进入 ImportLossReport。

报告分别比较符号/位号/引脚、网络连通、封装/焊盘映射、板框/层叠、铜与过孔、规则/变体/3D。成功解析不等于电气等价；设计规则与高级刚柔信息不可静默丢弃。Altium 原生文件无损往返是单独关键项目，当前不承诺。

## 插件协议（目标）

Descriptor 含 id、版本、支持 schema/API、capabilities、输入/输出类型、权限（read-project/write-proposal/network/execute-tool）和可执行文件哈希。插件以独立进程读取冻结输入，返回结构化结果/变更提案，不直接写权威源。

握手：protocolVersion、toolVersion、capabilities、units、licenseState；作业：jobID、revisionHash、inputFiles、parameters、timeout；结果：status、diagnostics、outputHashes、proposal、provenance。未知能力显式 unsupported，schema 错误为失败。

权限默认按本地最小能力配置，网络需用户显式操作授权；插件异常不可破坏主服务。任何写提案必须经过 expectedRevision/差异预览/批准/提交，不执行项目携带的任意脚本。

## CLI 与 IPC

现有 CLI 的退出码用于自动化：失败为非零，缺引擎/版本错误/报告违规不能返回成功。参数数组和 Unicode 路径需要负测试。IPC 应只用官方文档化 API，查询版本与支持对象；原理图或功能尚不支持时走原生 GUI，不能用脆弱鼠标宏宣称内核能力。

## 验收

坏 schema、旧/未来版本、超时/取消、日志大输出、恶意路径、未声明网络、修改已变更 revision、错误单位、插件崩溃和签名/许可缺失。导出和导入需独立工具互验证，不能仅由同一解析器自证。

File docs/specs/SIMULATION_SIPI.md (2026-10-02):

# SPICE、阻抗与 SI/PI

状态：SPICE 使用原生 KiCad；工作台仅提供薄导体微带初估。以下数值服务待实现，不能以 UI 或近似公式冒充专业求解器。

## SPICE 流程

模型从项目本地目录加载，递归 `.include/.lib` 的依赖闭包检查。实例引脚与子电路声明映射、单位和温度显式记录。JobSpec 绑定电路 revision、模型哈希、仿真器版本、DC/AC/Transient 参数、扫描条件、收敛选项。结果包含日志、波形单位和收敛状态；不收敛不生成可批准结论。

## 二维场求解

Input：截面几何、导体厚度/粗糙度、介质频率依赖、阻焊、回流平面、差分间距；Output：Z0/Zdiff/Zcommon、有效介电常数、损耗、传播延时和误差估计。适配器记录网格、边界条件和收敛曲线。至少用微带、带状、共面和差分黄金模型与独立基准核对。v0.1 Engineering.microstrip 是薄导体准静态近似，不支持上述复杂输入。

## SI 服务

网络拓扑由权威网表/PCB 抽取，包含走线层、长度、过孔、端接、驱动/接收 IBIS、封装和 S 参数。拓扑预览可审查。输出反射、串扰、眼图、时序与裕量；频率/单位/参考阻抗一致。DDR/SerDes/差分模型建立数值误差预算，结果回写长度/延时约束需用户批准。

## PI 服务

DC 压降需要铜厚、平面连通、过孔电阻、负载和电源边界；AC PDN 需要去耦模型/ESR/ESL、端口和网格。输出压降、电流密度、目标阻抗/谐振和收敛。不存在可靠材料/负载数据时返回 missing-input，不作“通过”判断。

## 性能和安全

独立进程运行求解器，限制内存/线程/超时，支持取消与部分日志，输入无写权限。结果不得修改原生板；建议转换成可审查 ECO。未知插件或许可证缺失应报告 unsupported，不静默切换更弱模型。

## 验收

模型单位/引脚异常、SPICE 收敛失败、网格加密收敛、参考精度、过孔/损耗/介质频散、眼图判定、PDN 场景、断网模型闭包、两架构数值差异、结果可复现和修改源后失效。未经工程专家审阅不能计入 SIM06–10。

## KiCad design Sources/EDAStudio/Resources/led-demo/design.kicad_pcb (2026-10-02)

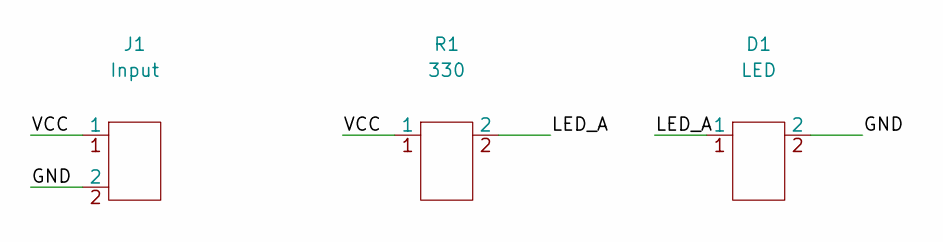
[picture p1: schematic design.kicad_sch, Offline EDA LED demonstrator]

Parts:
D1: LED; Axial2
J1: Input; Header2
R1: 330; Axial2

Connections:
/GND: D1.2, J1.2
/LED_A: D1.1, R1.2
/VCC: J1.1, R1.1

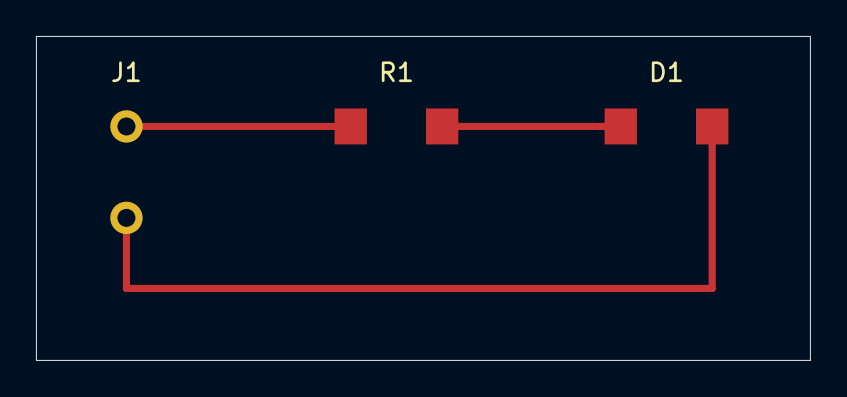
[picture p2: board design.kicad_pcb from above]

Board: 2 copper layers, 43.0 x 18.0 mm, 3 parts (0 on the bottom side), 3 nets.

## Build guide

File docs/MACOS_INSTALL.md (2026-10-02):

# macOS 安装、构建和发布

## 本地运行

工作台需要 macOS 14+。当前二进制验证在 arm64 完成；最低系统及 Intel 硬件仍待矩阵验收。KiCad 10 官方支持范围以官方页面为准，本工作台的最低版本要求比引擎更严格。

正式离线准备包含工作台 ZIP、官方 KiCad DMG、器件符号/封装、三维和 SPICE 模型、用户项目。v0.1 工作台 ZIP 只有工作台、资源、示例、文档；不包含完整引擎。

将工作台拖入 Applications，将官方 KiCad 文件夹按官方说明安装。默认 CLI 路径为 `/Applications/KiCad/KiCad.app/Contents/MacOS/kicad-cli`。自定义路径在工作台设置选择，CLI 用 KICAD_CLI。显式选择的路径失效时不会静默回退到另一引擎。

## 编译

```bash
xcode-select --install  # 仅在尚未安装开发工具时，由用户执行
./scripts/build-app.sh
```

脚本不安装系统依赖，资源本地同步，然后 SwiftPM release 编译。版本兼容问题可用 EDA_SDK 指定 SDK。产物包括 `.app`、ZIP 和 eda。完整 Xcode 不是核心测试的必要依赖；EDASelfTests 是可运行测试程序。

目前打包当前主机架构。未来 universal2 应分别在 arm64/x86_64 构建、检查依赖架构、合并，并在两种硬件运行；当前不宣称 universal2 已完成。

## 签名与公证

开发包用 `codesign --sign -` 的 ad-hoc 签名，没有 Developer ID 和公证票据。正式分发需要持有者的 Apple Developer 证书和凭据，不能伪造或随仓库提交。未来 release 作业应按顺序：资源组装 → frameworks 检查 → 内层组件签名 → 主应用签名 → 公证 → staple → 校验 → 断网安装验收。凭据使用 CI secrets/keychain，不写入代码。

## 更新/卸载

程序不会自动联网更新。手工替换 app；项目数据在用户选择的目录，删除 app 不删除工程。最近项目和引擎路径使用 macOS UserDefaults 保存。无需本地守护进程或开放 TCP 端口。

## 常见故障

- 缺引擎：检查目录布局，确保选择 `kicad-cli` 而不是 app 目录。
- 版本不支持：仅接受 10.x；9.x/未来主版本须新增验证后再放行。
- 编辑器找不到：完整 KiCad.app 内有 Contents/Applications/eeschema.app 和 pcbnew.app；不要仅复制 CLI。
- 缺模型：先安装完整资源或把自定义模型复制到工程并使用相对路径。
- 工程打不开：manifest 格式/schemaVersion 和所有设计路径必须位于项目内。
- 发布失败：查看 outputs/failed-* 的 release.json 和 ERC/DRC 报告；修复后新作业重跑。

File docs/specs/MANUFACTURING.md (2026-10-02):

# 制造发布与工程文档

## v0.1 已实现

唯一作业 UUID → 验证引擎 10.x → 复制源并核对前后/目标哈希 → 检查铜层仅双层 → ERC 全启用级别 → DRC 加原理图一致性 → 核对结构化报告为空 → Gerber/Excellon/坐标/设计 BOM/PDF → 可选 STEP → 核对源未改和输出非空 → 输出 SHA-256 清单 → move 成 release。

任一步失败保留 failed 目录和已经完成的命令日志，不能生成 release 目录。所有路径带参数数组传入，空格/中文不触发 shell。发布的 planning-bom.csv 单独命名，避免被当成设计权威 BOM。

注意启用的规则以项目和引擎为准；ignored_checks 列出关闭检查，不保证厂商所有 DFM 要求。真正制造文件审核仍需人工和独立工具。

## 目标专业输出

OutputJobSet 记录输入 revision、variant、stackup、工艺能力、模板、引擎/插件版本、作业依赖和交付件。必须包括所有铜层、板框、孔分组、坐标、极性、BOM、装配图、叠层和工厂参数。IPC-2581/ODB++ 输出经独立导入复核，不以非空作为等效认证。

DocsGenerator 以模板创建制造/装配图：可更新的板视图、剖面、尺寸、公差、孔表、叠层、位号、变体 DNP、材料/工艺备注和修订表。尺寸绑定稳定对象 ID，设计改动后失效锚点报错；不能维持旧尺寸并无提示生成新 PDF。

## 制造门禁扩展

1. 来源闭包和批准库完整。
2. ERC/DRC/PCB-原理图一致性通过，禁用规则/豁免有批准及理由。
3. 变体、BOM、坐标、装配图元件集合一致。
4. 层/钻孔/叠层/单位/原点完整；独立网表比较没有额外开短路。
5. 指定厂商 DFM 能力通过或逐条批准；没有“全部忽略”默认选项。
6. 源/输出/审批/工具全部绑定 releaseHash；验包失败禁止交付。

## 可重复性

输出哈希可能受引擎时间戳、排序、文档元数据影响。将语义几何/网表比较与字节哈希分开，不宣称所有导出 bit-for-bit deterministic。检查缓存必须包含源、库锁、规则和工具哈希。v0.1 不复用检查缓存。

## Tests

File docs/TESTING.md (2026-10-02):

# 验证策略与证据

## 本仓库现有测试

```bash
./scripts/swift.sh run EDASelfTests
KICAD_CLI=/path/to/kicad-cli python3 scripts/integration-test.py
python3 scripts/check-coverage.py
```

EDASelfTests 不依赖 XCTest。测试路径越界、符号链接、未知格式、拒绝覆盖、快照篡改、生成目录排除、BOM 组键/DNP/重复位号/价格、CSV 转义/公式防护、线束针脚规则、阻抗参考值、S-expression 错误/深度、预览几何、进程大输出/退出码/超时和报告格式。测试失败退出非零。

真实集成测试需要 KiCad 10：复制自包含项目到含中文和空格的路径，运行全部 12 种作业、制造发布和输出哈希核对；删除走线验证拒绝发布、模拟四层板验证不会漏内层、篡改快照验证拒绝。没有引擎时测试失败，不以 mock 假装真实通过。

reports/core-tests.json 与 integration.json 为运行证据；VALIDATION.md 描述平台、范围和剩余限制。零违规 LED 夹具不证明所有电气规则、多层或全部编辑器功能。

## 必需的后续测试层次

1. 单元：模型不变量、规则优先级、单位、网络连通、事务、引用闭包与错误恢复。
2. 黄金设计：层次电路、多单元、总线、2/4/16/32 层、BGA/HDI/差分调谐/刚柔/多板/线束，含明确正常/异常预期。
3. 互操作：独立 Gerber、钻孔、ODB++/IPC-2581/STEP 阅读器和制造合作方核对，不仅检查文件非空。
4. 编辑流程：两架构 Mac、人机操作、跨探测、撤销重做、保存重开、IPC 保存确认。
5. 故障：磁盘满、断电、子进程崩溃、取消、并发外部编辑、库缺失、坏数据、项目路径/编码。
6. 离线：系统封锁网络和抓包，完整从创建到制造/仿真/恢复流程，无在线许可依赖。
7. 性能：记录机型、系统、引擎、库、对象数、内存、P95 耗时、交互帧率，避免只给空项目数据。

## 90% 门禁

类别占比总和固定 100%。implemented/inherited/planned 都不能计入 verified。完整验收记录需 feature ID、平台、程序/引擎版本、夹具哈希、正负预期、独立验证、人工操作记录、结果和审阅批准。每类别 ≥80%、总分 ≥90%，关键 SI/PI/刚柔/多板/线束和单板/制造必须通过，且无未关闭的严重数据或开短路缺陷。

当前 check-coverage 输出 0% 是“完整验收分数尚未建立”，不代表程序不可运行或 KiCad 没有功能。代码实现与专业验收的区别必须保留。

## CI

基础 CI 编译、运行 EDASelfTests、验证功能数据、构建 app 并保留 artifact。可选人工触发 KiCad 集成工作流下载固定官方包并校验。签名公证与硬件/代工验收不在当前 CI 中。流水线失败不能自动把状态变为通过。

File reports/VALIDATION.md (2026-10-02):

# v0.1 验证记录

验证日期：2026-10-03（Asia/Tokyo）。环境：Apple Silicon arm64，Swift 6.4 / macOS SDK 26.5；系统原生编译。工作台目标 macOS 14+，最低系统与 Intel 仍需硬件验收。

## 实际检查

- Swift release/debug 编译与 app 打包，ad-hoc 签名严格校验。
- 打包 app 原生 UI：启动、资源加载、新建项目、双层/3 元件摘要、真实 PCB 预览、采购 DNP 保存/恢复、点对点线束页面；详见 ui-smoke.json。
- 18 个核心测试：路径越界/符号链接/格式/拒绝覆盖、快照哈希/篡改/排除生成目录、BOM/DNP/重复位号/价格/CSV、线束、阻抗参考值、解析器/预览非有限几何、进程大输出/退出码/超时、错误报告拒绝。
- 官方 KiCad 10.0.6 universal DMG，SHA-256 校验：ef4dcd4278c46d3efcd28c8db273d5957d68efda028f6bf79b4811fc5302dc68；只读挂载执行，不修改系统 KiCad 安装。
- 自包含原创 LED 夹具：ERC 零违规、DRC 零违规/零未连接/零原理图一致性问题。
- 集成测试：12 种真实 CLI 作业、冻结源的制造发布、源/输出 SHA-256、中文/空格路径、断线拒绝发布、四层板拒绝发布、快照篡改拒绝。结果以 integration.json 为准。

## 如何重现

```bash
./scripts/prepare-resources.sh
./scripts/swift.sh build
EDA_TEST_REPORT=reports/core-tests.json ./scripts/swift.sh run EDASelfTests
KICAD_CLI=/path/to/kicad-cli python3 scripts/integration-test.py
./scripts/build-app.sh
python3 scripts/check-coverage.py
```

## 本证据的边界

单个双层演示项目。输出非空和可重算哈希不等于所有专业格式被独立制造工具验证。复杂多层板、SPICE 模型、完整图形编辑、SI/PI、刚柔、多板、正式变体、代工 DFM、最低系统、Intel、签名公证和系统封网/抓包尚未完整验收。因此没有把任意矩阵功能提前标记 verified，也没有宣称达到 Altium 90%。

引擎 stderr 有 Fontconfig 缓存版本提示，未阻止实际检查/导出；属于官方安装包资源环境提示，日志仍保留。固定引擎版本与测试输入随仓库说明，复跑结果可能包含时间戳差异。

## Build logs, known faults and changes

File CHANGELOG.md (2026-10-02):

# 变更日志

## 0.1.1 — 2026-10-03

明确区分 Double 与 CGFloat，修复 GitHub macOS 14 旧版 Swift 工具链的 PCB 预览编译歧义。

## 0.1.0 — 2026-10-03

首个原生 macOS 基础工作台与完整研发设计。

包含项目/CLI、BOM/线束、快照、简化 PCB 预览、KiCad 10 本地作业和双层制造发布门禁；原创自包含 LED 示例；122 项功能矩阵、架构/数据/高级模块规格、路线图和离线/验收文档；核心及真实引擎集成测试；app 打包与 CI。

尚未达到 Altium Designer 90% 完整功能。复杂库依赖闭包、正式变体、SI/PI、机电同步、多板、刚柔结合、专业文档与两架构完整验收待后续阶段。
